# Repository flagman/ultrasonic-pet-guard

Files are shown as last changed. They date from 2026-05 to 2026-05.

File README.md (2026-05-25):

# Ultrasonic Pet Guard

An open-source, 3D-printed **ultrasonic deterrent for dogs and cats**, built around an ESP32. A PIR sensor watches a zone (a doorway, a couch, a corner the dog keeps marking); when it detects motion during the active hours, the device fires a short burst of loud **25 kHz** sound — inaudible to humans, very unpleasant to the animal — so the pet learns to stay away.

It is deliberately *loud*. The ESP32 drives the ultrasonic transducer through an L298N in a **full H-bridge** off a **12 V** supply, which is what makes the burst strong enough that a dog will actually break off and leave the zone rather than just twitch an ear.

| Real device | Concept render | Fusion 360 (CAD) |
|---|---|---|
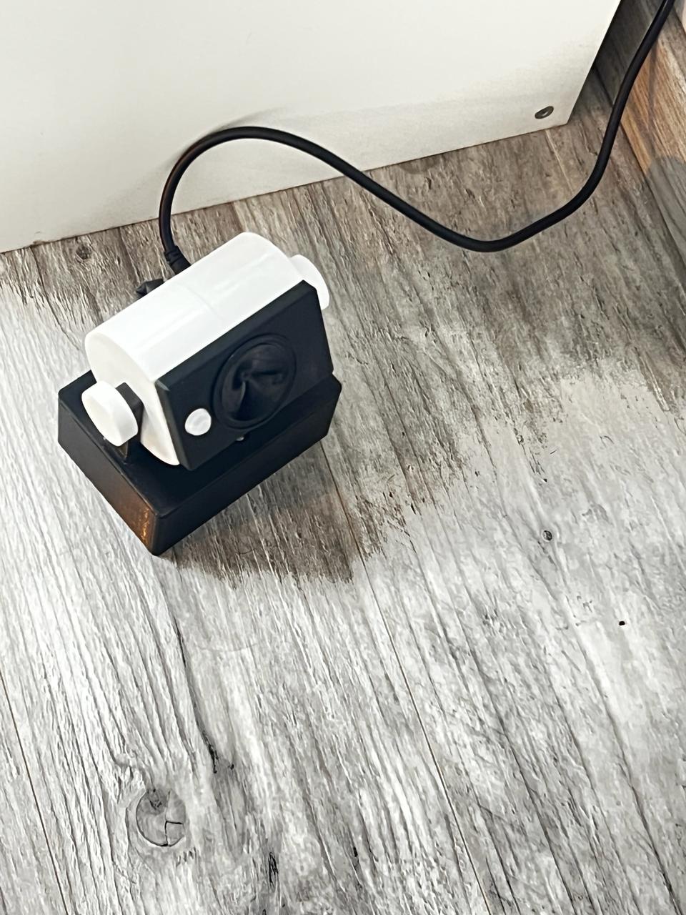
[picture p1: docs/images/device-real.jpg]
Real 3D-printed device
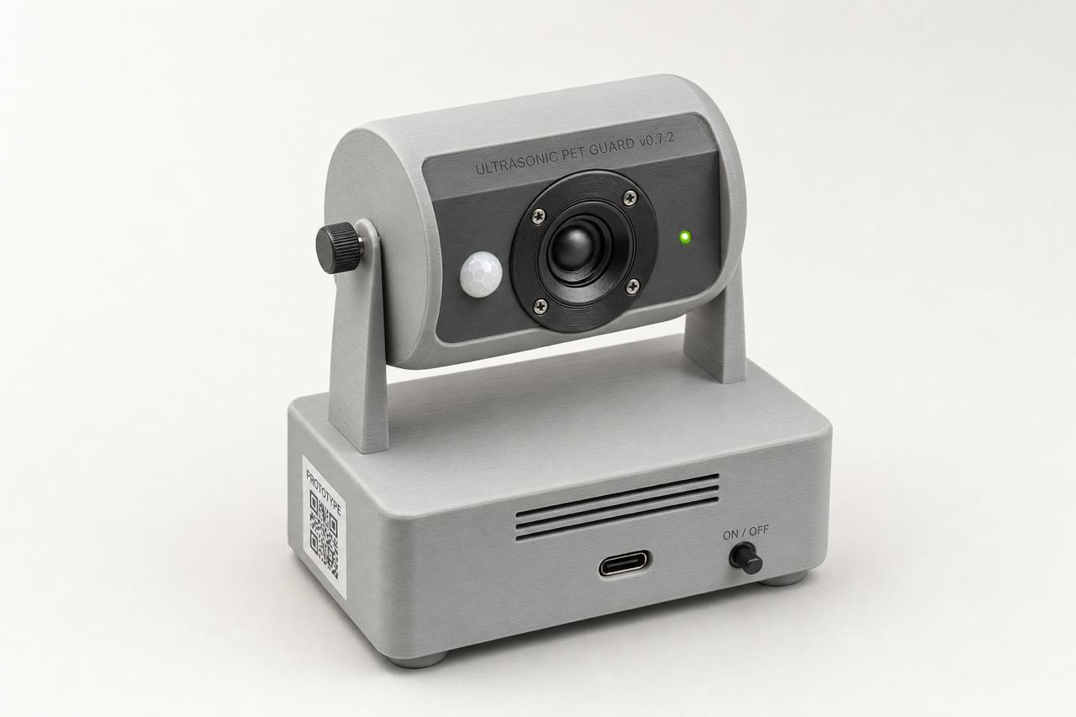
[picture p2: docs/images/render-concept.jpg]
Studio concept render
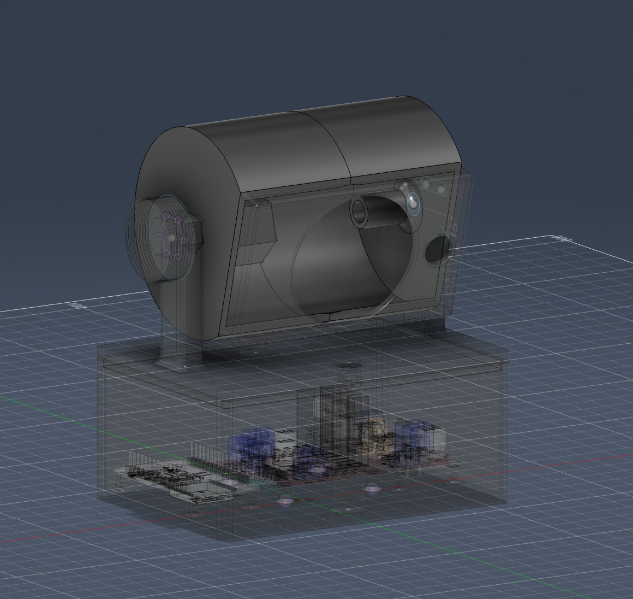
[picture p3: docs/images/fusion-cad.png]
Fusion 360 CAD view
|  |  |  |

> ⚠️ **Use responsibly.** This is an aversive device. It is meant to keep a pet out of a specific spot, not to punish or harm. Only run it on the active-hours schedule, point it at the zone (not at where the animal rests/sleeps), and dial back the burst if your pet is simply distressed rather than redirected. Do not aim it at people or use it where it could affect other animals you don't intend to.

---

## How it works (and why it hits so hard)

Several design choices stack up to make the output far stronger than a typical AliExpress repeller:

- **Full H-bridge drive (±Vsupply instead of 0..Vsupply).** The L298N is driven with IN1 carrying the PWM and IN3 carrying the *inverted* PWM (routed through the ESP32 GPIO matrix). The transducer sees the full supply swing in *both* directions — that's 2× the voltage swing, ≈4× the acoustic power, **+6 dB** for free versus a single-ended driver.
- **12 V supply.** Running the H-bridge at 12 V (not 5 V) raises the SPL much further again — this is the single biggest reason the built device is so loud.
- **Hardware PWM (LEDC).** The 25 kHz square wave is generated by the ESP32's hardware timer, so the frequency is rock-steady with no software jitter.
- **25 kHz, chosen empirically.** Inaudible to humans (>20 kHz), well within a dog's hearing, and reproduced efficiently by a real ultrasonic piezo tweeter. 25 kHz gave the sharpest real-world reaction in testing.
- **Pulsed burst, not a steady tone.** 10 pulses of 300 ms with 150 ms gaps. The on/off pattern triggers a startle response and prevents the animal from habituating the way it would to a continuous tone.
- **Dedicated ultrasonic piezo transducer**, well sealed in the enclosure and aimed outward, so the energy goes into the room instead of leaking back inside the case.

See [`docs/HARDWARE.md`](docs/HARDWARE.md) for the parts list (BOM), wiring, and print settings.

## Features

- PIR-triggered 25 kHz ultrasonic burst (10 × 300 ms).
- **Web UI** over WiFi (`http://pet-guard.local/`) to set the active-hours window and fire a test burst.
- **NTP-synced schedule** (e.g. 21:00 → 07:00, may cross midnight), stored in NVS so it survives reboots.
- **Fail-safe:** if WiFi/NTP is unavailable, the device runs 24/7 instead of going dark.
- JSON status endpoint at `/api/status`.
- Tilting "drum head" on a friction-clamped M8 pivot bolt so you can aim it precisely.

## Repository layout

```
.
├── src/main.cpp                 ESP32 firmware (PlatformIO / Arduino framework)
├── include/
│   ├── config.example.h         WiFi credentials template — copy to config.h
│   └── config.h                 your local credentials (gitignored)
├── platformio.ini               PlatformIO project config
├── hardware/
│   ├── cad/                     Fusion 360 STEP export
│   └── print/                   ready-to-slice 3MF parts
├── docs/
│   ├── HARDWARE.md              BOM, wiring, and print settings
│   └── images/                  photos & renders
└── README.md
```

## Bill of materials

### Electronics

| Qty | Part | Notes |
|---|---|---|
| 1 | ESP32 DevKit (ESP32-WROOM-32) | the controller |
| 1 | L298N dual H-bridge module | drives the transducer in full H-bridge |
| 1 | AM312 PIR motion sensor | 3-pin (VCC / GND / OUT) |
| 1 | Wide-band piezo tweeter, Ø50 mm | pick a unit that reproduces well past 25 kHz (e.g. **~1–45 kHz**), **not** one capped at 25 kHz; bonded in with hot-melt glue |
| 1 | **12 V DC power adapter, ≥1–2 A** | powers the H-bridge at 12 V (high SPL) |
| 1 | **12 V barrel-jack socket** (panel mount, 5.5 × 2.1 mm) | power input on the enclosure |
| 1 | **DC-DC step-down (buck) converter — XL4015** | drops 12 V → 5 V for the ESP32, PIR, and L298N logic |
| ~3 m | Hookup wire (AWG 28–30) + heat-shrink | internal wiring harness |

> The build is powered by **12 V via the barrel jack**. The 12 V feeds the L298N motor supply (`Vs`) directly (for high SPL), while an **XL4015 buck converter steps 12 V down to 5 V**. That single 5 V rail powers the **ESP32 (`5V` pin), the PIR sensor (`VCC`), and the L298N logic (`+5V`)** — so the L298N's onboard 5 V regulator is not used (set the XL4015 output trimmer to 5 V before connecting anything). During flashing you can also power the ESP32 over USB.

> **Note:** the power LED and on/off switch visible in the concept render are **not** part of the current enclosure design (no cutouts or mounts, and the firmware does not drive an LED). Power is switched at the 12 V adapter. Add your own panel cutouts if you want them.

### 3D-printed parts (`hardware/print/`)

| File | Part |
|---|---|
| `body.3mf` | base shell (electronics bay) |
| `top-plate.3mf` | top plate / head module with yokes |
| `drum-left.3mf`, `drum-right.3mf` | drum-head halves |
| `front-panel.3mf` | front insert / chord face (PIR + transducer cutouts) |
| `bolt-holder.3mf` | tilt pivot / captured M8-nut holder |

Print in **PETG**, 0.2 mm layers, 100 % infill. Print settings and the part list are in [`docs/HARDWARE.md`](docs/HARDWARE.md).

### Fasteners & hardware

| Qty | Part | Notes |
|---|---|---|
| 2 | **M8 bolt** | tilt pivot — one through each yoke |
| 1 | **M8 extended (coupling) nut** | captured in one drum end; the M8 tilt bolt threads into it to clamp the tilt by friction (the other drum end is a plain Ø8 hole) |
| 1 | **M3 heat-set brass insert** | holds the top-plate |
| 6–8 | **Ø1.75 mm self-tapping plastic screws** | mounting the PCBs (ESP32 / L298N / XL4015) |
| 1 | cable grommet Ø10 mm | base↔drum harness pass-through |
| 4 | self-adhesive rubber feet | base |
| — | **Hot-melt glue** | bonding the PIR sensor + tweeter into the front panel |
| — | **Superglue (CA)** | joining the two drum halves + the front panel |

## Firmware: build & flash (PlatformIO)

1. Install [PlatformIO](https://platformio.org/) (VS Code extension or `pip install platformio`).
2. Set your WiFi credentials (kept out of git):
   ```sh
   cp include/config.example.h include/config.h
   # then edit include/config.h with your SSID and password
   ```
   WiFi is optional — it is only used for NTP (the schedule) and the web UI. Without it the device runs 24/7.
3. Connect the ESP32 over USB and build + upload:
   ```sh
   pio run --target upload
   ```
4. Watch the serial log (optional):
   ```sh
   pio device monitor -b 115200
   ```

## Wiring / pinout

| Signal | ESP32 GPIO | To |
|---|---|---|
| PIR `OUT` | **27** | AM312 OUT |
| L298N `IN1` | **13** | H-bridge input (non-inverted PWM) |
| L298N `IN3` | **12** | H-bridge input (inverted PWM, via GPIO matrix) |
| L298N `ENA` (+`ENB`) | **14** | shared H-bridge enable |
| L298N `IN2`, `IN4` | — | **tie both to GND** (unused half-bridge inputs — must not float) |
| Transducer | — | across L298N **OUT1 ↔ OUT3** |
| 12 V rail | — | barrel jack → L298N `Vs` (motor supply) **and** → XL4015 buck input |
| 5 V rail (XL4015 `OUT`) | — | → ESP32 `5V`, → PIR `VCC`, **and** → L298N `+5V` logic |

The piezo is connected **between OUT1 and OUT3** (not to ground) — that is what gives the full H-bridge ±12 V swing. Only `IN1`/`IN3` are driven; the other two inputs `IN2` and `IN4` (which control the unused outputs OUT2/OUT4) must be **tied to GND** so they don't float and cause erratic switching.

## Using it

- Open **`http://pet-guard.local/`** (or the IP printed on the serial log) from any phone/laptop on the same network.
- Set the **active window** (default 21:00 → 07:00; it may cross midnight), toggle **Enabled**, and **Save** — the schedule is stored on the device.
- Hit **Test (fire burst now)** to verify the transducer. You won't hear the 25 kHz tone; confirm it with a spectrum-analyzer phone app, or just watch the pet's reaction.

## License

[MIT](LICENSE) — firmware, hardware files, and documentation. Build it, modify it, share it.

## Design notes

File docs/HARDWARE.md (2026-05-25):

# Ultrasonic Pet Guard — Hardware

Parts list, wiring, and print settings. The geometry and assembly are defined by
the CAD (`hardware/cad/`) and the print files (`hardware/print/`).

## Electronics

| Component | Key spec |
|---|---|
| ESP32 DevKit | ESP32-WROOM-32, USB-C (~52 × 28.7 mm) |
| L298N dual H-bridge module | with heatsink (~43.5 × 43.5 × 26 mm) |
| AM312 PIR sensor | 3-pin (VCC / GND / OUT), dome Ø13.4 mm |
| Wide-band piezo tweeter | Ø50 × 18 mm, ~1–45 kHz (must reproduce 25 kHz well — **not** a unit capped at 25 kHz) |
| 12 V DC adapter | ≥ 1–2 A, 5.5 × 2.1 mm barrel plug |
| 12 V barrel-jack socket | panel-mount, 5.5 × 2.1 mm |
| XL4015 DC-DC buck | 12 V → 5 V step-down |
| Silicone hookup wire + heat-shrink | AWG 28–30, ~3 m |

> The LED and on/off switch shown in the concept render are **not** in the current enclosure design (no cutouts; firmware drives no LED). Power is switched at the adapter.

## Fasteners & adhesives

| Part | Qty | Use |
|---|---|---|
| M8 bolt | 2 | tilt pivot (one per yoke) |
| M8 extended (coupling) nut | 1 | captured in one drum end; the M8 bolt threads into it (other end is a plain Ø8 hole) |
| M3 heat-set brass insert | 1 | holds the top-plate |
| M2.5 × 6 countersunk screw | 4 | bottom cover ↔ base |
| Ø1.75 mm self-tapping screws | 6–8 | ESP32, L298N, XL4015 into the printed standoffs |
| Cable grommet Ø10 mm | 1 | base↔drum harness pass-through |
| Rubber feet | 4 | base |
| Hot-melt glue | — | PIR + tweeter into the front panel |
| Superglue (CA) | — | drum halves + front panel |

## Wiring

**Pinout (ESP32):**

| GPIO | To |
|---|---|
| 27 | PIR `OUT` |
| 13 | L298N `IN1` (PWM) |
| 12 | L298N `IN3` (inverted PWM, via GPIO matrix) |
| 14 | L298N `ENA` + `ENB` |

- L298N `IN2` and `IN4` → **GND** (unused inputs, must not float).
- Transducer connects **across L298N OUT1 ↔ OUT3** (full H-bridge).

**Power:**

```
12 V adapter → barrel jack ─┬→ L298N Vs (12 V → H-bridge / piezo)
                            └→ XL4015 buck (12 V → 5 V) ─┬→ ESP32 5V
                                                          ├→ L298N +5V (logic)
                                                          └→ PIR VCC
common GND
```

Set the XL4015 output trimmer to 5 V before wiring it to anything. The L298N's onboard 5 V regulator is not used.

## Printing

- FDM, 0.4 mm nozzle, **PETG**.
- Layers: **0.2 mm** (all parts).
- Infill: **100 %**.
- Print files (`hardware/print/`): `body`, `top-plate`, `drum-left`, `drum-right`, `front-panel`, `bolt-holder`.

## Assembly notes

- The ESP32 is mounted **upside down** in the base (board flipped onto its standoffs).
- Heat-set the single M3 insert into the base that holds the top-plate; capture the extended M8 nut in one drum end.
- Hot-glue the PIR and the tweeter into the front panel; superglue the two drum halves and the front panel.
- Route the harness out through the drum's hollow stub axle and the base grommet before closing up.
- Mount the drum on the two M8 bolts; tighten the bolt on the captured-nut side to set the tilt friction.

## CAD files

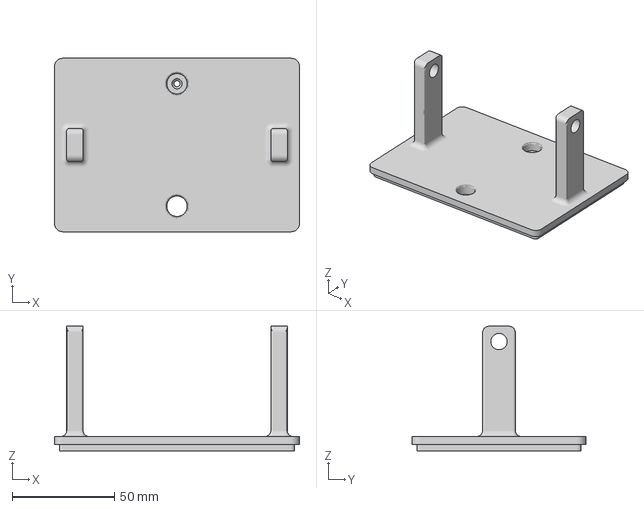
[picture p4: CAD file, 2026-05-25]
hardware/print/top-plate.3mf
120.0 x 85.0 x 61.0 mm

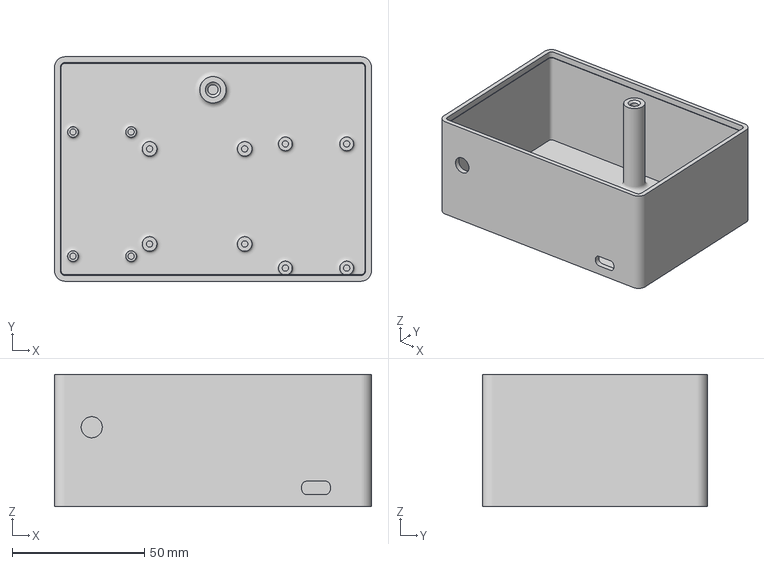
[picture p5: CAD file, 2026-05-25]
hardware/print/body.3mf
120.0 x 85.0 x 50.0 mm

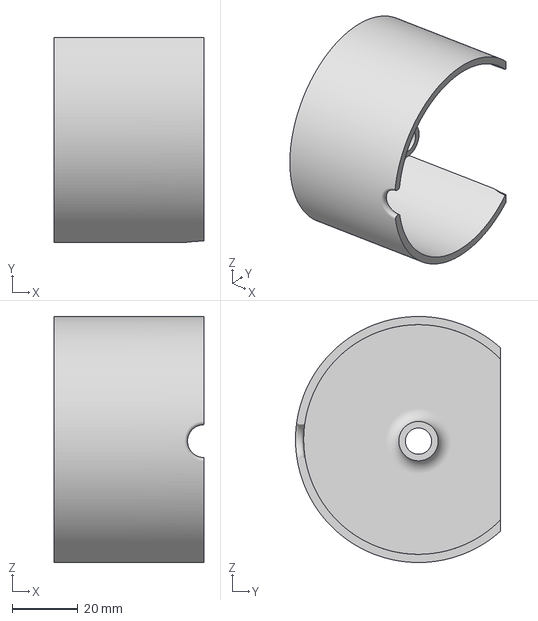
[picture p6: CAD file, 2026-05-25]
hardware/print/drum-right.3mf
45.7 x 62.5 x 75.0 mm

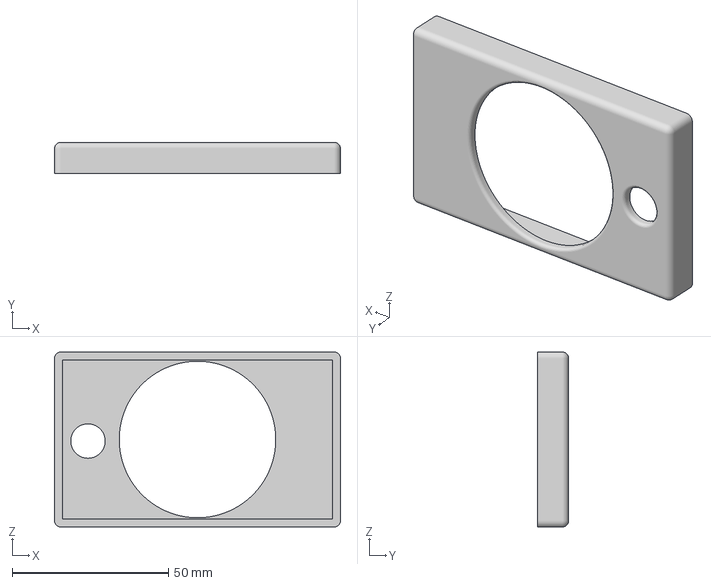
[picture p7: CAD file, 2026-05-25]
hardware/print/front-panel.3mf
91.4 x 10.0 x 55.9 mm

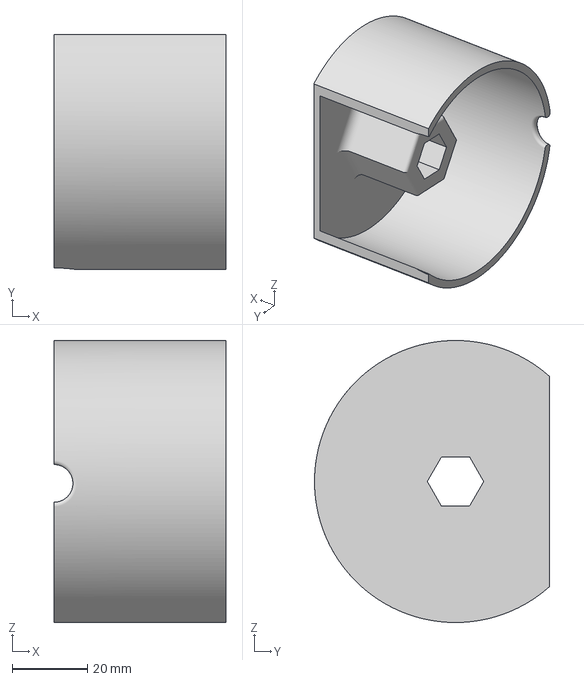
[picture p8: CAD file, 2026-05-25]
hardware/print/drum-left.3mf
45.7 x 62.5 x 75.0 mm

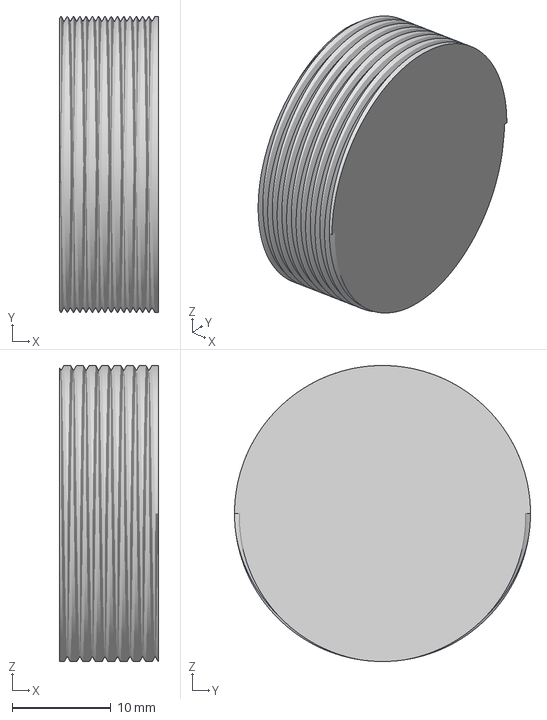
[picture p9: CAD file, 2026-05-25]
hardware/print/bolt-holder.3mf
10.0 x 30.0 x 30.0 mm

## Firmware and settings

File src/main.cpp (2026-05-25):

#include <Arduino.h>
#include <WiFi.h>
#include <WebServer.h>
#include <ESPmDNS.h>
#include <Preferences.h>
#include <time.h>
#include <rom/gpio.h>             // gpio_matrix_out — routes a peripheral signal onto a GPIO
#include <soc/gpio_sig_map.h>     // LEDC_HS_SIG_OUT0_IDX — LEDC signal index
#include "config.h"               // WiFi credentials (copied from config.example.h, gitignored)

void playUltrasound(int durationMs);
void playTone(uint32_t freqHz, int durationMs);
bool isActiveNow();
void fireBurst();
void loadSchedule();
void saveSchedule();
void handleRoot();
void handleSave();
void handleTest();
void handleStatus();
// ==========================================
// ULTRASONIC BARRIER FOR DOGS (ESP32)
// ==========================================

// Pin assignments
const int pirPin = 27;    // AM312 motion sensor
const int in1Pin = 13;   // L298N IN1 — LEDC, non-inverted
const int in3Pin = 12;   // L298N IN3 — LEDC, inverted (full H-bridge between OUT1 and OUT3)
const int enaPin = 14;    // L298N ENA + ENB (tied together on the module) — shared enable
// NOTE: L298N IN2 and IN4 (the unused half-bridge inputs driving OUT2/OUT4) are
// tied to GND in hardware so they don't float. They are not driven by the ESP32.

// LEDC: ESP32 hardware PWM (generates the square wave itself, no jitter from FreeRTOS)
const int ledcChannel = 0;
const int ledcFreqUltrasound = 25000;  // 25 kHz — operating frequency
const int ledcResolution = 8;          // 8-bit: duty 0..255

// --- WiFi / NTP ---
const char* wifiSsid     = WIFI_SSID;      // defined in config.h
const char* wifiPassword = WIFI_PASSWORD;  // defined in config.h
const char* ntpServer    = "pool.ntp.org";
// POSIX TZ for Warsaw: CET (UTC+1) in winter, CEST (UTC+2) in summer.
// M3.5.0 = last Sunday of March, M10.5.0/3 = last Sunday of October at 03:00.
const char* tzPosix      = "CET-1CEST,M3.5.0,M10.5.0/3";

// --- Active operating window (editable through the web UI) ---
uint8_t startHour   = 21;
uint8_t startMinute = 0;
uint8_t endHour     = 7;
uint8_t endMinute   = 0;
bool    scheduleEnabled = true;   // global kill switch
unsigned long lastTriggerMs = 0;  // shown in the UI

// Flag: did the time sync succeed? If not, run 24/7 (fail-safe).
bool timeSynced = false;

// --- Web server + NVS ---
WebServer   server(80);
Preferences prefs;
const char* mdnsHost = "pet-guard";  // → http://pet-guard.local

void setup() {
  Serial.begin(115200);
  delay(100);
  Serial.println();
  Serial.println("=== Ultrasonic Pet Guard ===");
  Serial.printf("PIR: GPIO %d | IN1: GPIO %d | IN3: GPIO %d | ENA: GPIO %d\n",
                pirPin, in1Pin, in3Pin, enaPin);
  Serial.printf("LEDC: ch %d, freq %d Hz, %d-bit\n",
                ledcChannel, ledcFreqUltrasound, ledcResolution);

  // Load the schedule from NVS (defaults: 21:00 → 07:00, enabled).
  loadSchedule();
  Serial.printf("Loaded schedule: %02u:%02u - %02u:%02u, enabled=%s\n",
                startHour, startMinute, endHour, endMinute,
                scheduleEnabled ? "yes" : "no");

  // Pin setup
  pinMode(pirPin, INPUT);
  pinMode(in1Pin, OUTPUT);
  pinMode(in3Pin, OUTPUT);
  pinMode(enaPin, OUTPUT);

  // Make sure the speaker AND the amplifier are off at boot
  digitalWrite(in1Pin, LOW);
  digitalWrite(in3Pin, LOW);
  digitalWrite(enaPin, LOW); // hard-mute the L298N!

  // LEDC: one channel, two pins driven in antiphase.
  // IN1 gets the direct square wave; IN3 gets the same signal inverted
  // through the ESP32 GPIO matrix. This forms a full H-bridge between OUT1
  // and OUT3, i.e. ±Vsupply across the piezo instead of 0..Vsupply (+6 dB).
  ledcSetup(ledcChannel, ledcFreqUltrasound, ledcResolution);
  ledcAttachPin(in1Pin, ledcChannel);
  gpio_matrix_out(in3Pin, LEDC_HS_SIG_OUT0_IDX + ledcChannel, true, false);
  ledcWrite(ledcChannel, 0); // silent at boot (ENA is LOW anyway)

  // --- WiFi + NTP ---
  Serial.printf("Connecting to WiFi \"%s\"", wifiSsid);
  WiFi.mode(WIFI_STA);
  WiFi.begin(wifiSsid, wifiPassword);
  unsigned long wifiStart = millis();
  while (WiFi.status() != WL_CONNECTED && millis() - wifiStart < 15000) {
    delay(500);
    Serial.print(".");
  }
  Serial.println();

  if (WiFi.status() == WL_CONNECTED) {
    Serial.printf("WiFi OK, IP: %s, RSSI: %d dBm\n",
                  WiFi.localIP().toString().c_str(), WiFi.RSSI());

    configTzTime(tzPosix, ntpServer);
    struct tm tinfo;
    if (getLocalTime(&tinfo, 5000)) {
      timeSynced = true;
      Serial.printf("Time synced: %04d-%02d-%02d %02d:%02d:%02d %s\n",
                    tinfo.tm_year + 1900, tinfo.tm_mon + 1, tinfo.tm_mday,
                    tinfo.tm_hour, tinfo.tm_min, tinfo.tm_sec,
                    tinfo.tm_isdst > 0 ? "CEST" : "CET");
      Serial.printf("Active window: %02u:%02u - %02u:%02u\n",
                    startHour, startMinute, endHour, endMinute);
    } else {
      Serial.println("NTP sync failed — falling back to 24/7 mode");
    }

    // mDNS: open http://pet-guard.local/ from a phone/laptop browser.
    if (MDNS.begin(mdnsHost)) {
      MDNS.addService("http", "tcp", 80);
      Serial.printf("mDNS started: http://%s.local/\n", mdnsHost);
    } else {
      Serial.println("mDNS start failed");
    }

    server.on("/",          HTTP_GET,  handleRoot);
    server.on("/save",      HTTP_POST, handleSave);
    server.on("/test",      HTTP_POST, handleTest);
    server.on("/api/status", HTTP_GET, handleStatus);
    server.begin();
    Serial.printf("Web UI: http://%s/\n", WiFi.localIP().toString().c_str());
  } else {
    Serial.println("WiFi failed — falling back to 24/7 mode, no web UI");
  }

  // Give the motion sensor time to calibrate
  Serial.println("PIR warmup (2s)...");
  delay(2000);
  Serial.println("Ready. Waiting for motion.");
}

// Active operating window (minute resolution, may cross midnight).
// If the time is not synced — always active (fail-safe), but only when scheduleEnabled.
bool isActiveNow() {
  if (!scheduleEnabled) return false;
  if (!timeSynced) return true;
  struct tm tinfo;
  if (!getLocalTime(&tinfo, 50)) return true;

  int nowMins   = tinfo.tm_hour * 60 + tinfo.tm_min;
  int startMins = startHour     * 60 + startMinute;
  int endMins   = endHour       * 60 + endMinute;

  if (startMins == endMins) return false;                 // empty window
  if (startMins <  endMins) return nowMins >= startMins && nowMins < endMins;
  return nowMins >= startMins || nowMins < endMins;       // crosses midnight
}

// Load/save the schedule in NVS (survives reboots).
void loadSchedule() {
  prefs.begin("pet-guard", true);  // read-only
  startHour       = prefs.getUChar("sH", 21);
  startMinute     = prefs.getUChar("sM", 0);
  endHour         = prefs.getUChar("eH", 7);
  endMinute       = prefs.getUChar("eM", 0);
  scheduleEnabled = prefs.getBool("on",  true);
  prefs.end();
}

void saveSchedule() {
  prefs.begin("pet-guard", false); // RW
  prefs.putUChar("sH", startHour);
  prefs.putUChar("sM", startMinute);
  prefs.putUChar("eH", endHour);
  prefs.putUChar("eM", endMinute);
  prefs.putBool ("on", scheduleEnabled);
  prefs.end();
}

// A burst of 10 ultrasonic pulses. Factored out so it can be triggered both
// from loop() and from the "Test" button in the web UI.
void fireBurst() {
  lastTriggerMs = millis();
  for (int i = 0; i < 10; i++) {
    playUltrasound(300);
    delay(150);
  }
}

// ----- Web handlers ---------------------------------------------------------

static String hhmm(uint8_t h, uint8_t m) {
  char buf[6];
  snprintf(buf, sizeof(buf), "%02u:%02u", h, m);
  return String(buf);
}

void handleRoot() {
  struct tm tinfo;
  bool haveTime = timeSynced && getLocalTime(&tinfo, 50);
  String nowStr = haveTime
    ? String(tinfo.tm_hour < 10 ? "0" : "") + tinfo.tm_hour + ":" +
      String(tinfo.tm_min  < 10 ? "0" : "") + tinfo.tm_min
    : String("--:--");
  bool active = isActiveNow();

  String html;
  html.reserve(2500);
  html += F(
    "<!doctype html><html><head><meta charset=\"utf-8\">"
    "<meta name=\"viewport\" content=\"width=device-width,initial-scale=1\">"
    "<title>Pet Guard</title>"
    "<style>"
    "body{font-family:system-ui,sans-serif;max-width:420px;margin:24px auto;"
    "padding:0 16px;color:#1f2937}"
    "h1{font-size:20px;margin:0 0 16px}"
    "fieldset{border:1px solid #e5e7eb;border-radius:8px;padding:12px 16px;"
    "margin:0 0 16px}"
    "legend{font-size:13px;color:#6b7280;padding:0 6px}"
    "label{display:block;margin:10px 0 4px;font-size:14px}"
    "input[type=time]{font-size:18px;padding:6px 8px;width:130px;"
    "border:1px solid #d1d5db;border-radius:6px}"
    "button{padding:10px 16px;font-size:15px;border-radius:6px;border:0;"
    "background:#2563eb;color:#fff;cursor:pointer;width:100%}"
    "button.secondary{background:#64748b;margin-top:12px}"
    ".badge{display:inline-block;padding:6px 10px;border-radius:999px;"
    "font-size:13px;font-weight:600}"
    ".on{background:#dcfce7;color:#166534}"
    ".off{background:#fee2e2;color:#991b1b}"
    ".row{display:flex;align-items:center;gap:8px;margin:6px 0}"
    ".muted{color:#6b7280;font-size:13px;margin-top:8px}"
    "</style></head><body>"
    "<h1>Ultrasonic Pet Guard</h1>"
  );
  html += "<div class=\"row\"><span class=\"badge ";
  html += active ? "on\">ACTIVE" : "off\">IDLE";
  html += "</span><span>Now: <b>" + nowStr + "</b>";
  if (haveTime) html += tinfo.tm_isdst > 0 ? " CEST" : " CET";
  html += "</span></div>";

  html += "<form action=\"/save\" method=\"POST\"><fieldset><legend>Schedule</legend>";
  html += "<label><input type=\"checkbox\" name=\"enabled\"";
  if (scheduleEnabled) html += " checked";
  html += "> Enabled</label>";
  html += "<label>Start time</label><input type=\"time\" name=\"start\" value=\"" + hhmm(startHour, startMinute) + "\">";
  html += "<label>End time</label><input type=\"time\" name=\"end\" value=\"" + hhmm(endHour, endMinute) + "\">";
  html += "<div class=\"muted\">Window may cross midnight (e.g. 21:00 → 07:00).</div>";
  html += "</fieldset><button type=\"submit\">Save</button></form>";

  html += "<form action=\"/test\" method=\"POST\">"
          "<button class=\"secondary\" type=\"submit\">Test (fire burst now)</button></form>";

  html += "<p class=\"muted\">WiFi: " + WiFi.SSID() + " (" + WiFi.RSSI() + " dBm)<br>";
  html += "IP: " + WiFi.localIP().toString() + "<br>";
  html += "Uptime: " + String(millis() / 1000) + " s</p>";
  html += "</body></html>";

  server.send(200, "text/html; charset=utf-8", html);
}

static bool parseHHMM(const String& s, uint8_t& h, uint8_t& m) {
  int colon = s.indexOf(':');
  if (colon < 1) return false;
  int hh = s.substring(0, colon).toInt();
  int mm = s.substring(colon + 1).toInt();
  if (hh < 0 || hh > 23 || mm < 0 || mm > 59) return false;
  h = (uint8_t)hh;
  m = (uint8_t)mm;
  return true;
}

void handleSave() {
  uint8_t sH, sM, eH, eM;
  if (!parseHHMM(server.arg("start"), sH, sM) ||
      !parseHHMM(server.arg("end"),   eH, eM)) {
    server.send(400, "text/plain", "Bad time format");
    return;
  }
  startHour       = sH;
  startMinute     = sM;
  endHour         = eH;
  endMinute       = eM;
  scheduleEnabled = server.hasArg("enabled");
  saveSchedule();

  Serial.printf("Schedule updated: %s -> %s, enabled=%s\n",
                hhmm(startHour, startMinute).c_str(),
                hhmm(endHour,   endMinute).c_str(),
                scheduleEnabled ? "yes" : "no");

  server.sendHeader("Location", "/", true);
  server.send(303);
}

void handleTest() {
  Serial.println("Manual test fire (web)");
  fireBurst();
  server.sendHeader("Location", "/", true);
  server.send(303);
}

void handleStatus() {
  struct tm tinfo;
  bool haveTime = timeSynced && getLocalTime(&tinfo, 50);
  String json = "{";
  json += "\"enabled\":";        json += scheduleEnabled ? "true" : "false";
  json += ",\"active\":";        json += isActiveNow()    ? "true" : "false";
  json += ",\"start\":\"" + hhmm(startHour, startMinute) + "\"";
  json += ",\"end\":\""   + hhmm(endHour,   endMinute)   + "\"";
  json += ",\"now\":\"";
  if (haveTime) {
    char buf[20];
    snprintf(buf, sizeof(buf), "%04d-%02d-%02dT%02d:%02d:%02d",
             tinfo.tm_year + 1900, tinfo.tm_mon + 1, tinfo.tm_mday,
             tinfo.tm_hour, tinfo.tm_min, tinfo.tm_sec);
    json += buf;
  }
  json += "\",\"uptimeMs\":";   json += millis();
  json += ",\"lastTriggerMs\":"; json += lastTriggerMs;
  json += ",\"rssi\":";          json += WiFi.RSSI();
  json += "}";
  server.send(200, "application/json", json);
}

void loop() {
  server.handleClient();  // service HTTP requests (no-op if WiFi never came up)

  static int lastPirState = LOW;
  int pirState = digitalRead(pirPin);

  if (pirState != lastPirState) {
    Serial.printf("[%lu ms] PIR -> %s\n", millis(), pirState ? "HIGH" : "LOW");
    lastPirState = pirState;
  }

  if (pirState == HIGH) {
    if (!isActiveNow()) {
      struct tm tinfo;
      if (getLocalTime(&tinfo, 50)) {
        Serial.printf("[%02d:%02d] Motion ignored (window %02u:%02u-%02u:%02u, enabled=%s)\n",
                      tinfo.tm_hour, tinfo.tm_min,
                      startHour, startMinute, endHour, endMinute,
                      scheduleEnabled ? "yes" : "no");
      }
      delay(1000); // light debounce so the log isn't flooded
      return;
    }

    Serial.println("Motion! Firing ultrasound burst (10 x 300ms)");
    fireBurst();

    Serial.println("Cooldown 5s...");
    // 5 s cooldown, but keep answering HTTP (sliced into 50 ms delays)
    unsigned long until = millis() + 5000;
    while ((long)(millis() - until) < 0) {
      server.handleClient();
      delay(50);
    }
    Serial.println("Ready.");
  }
}

// -------------------------------------------------------------------
// ULTRASOUND generation (25 kHz) — inaudible to humans
// -------------------------------------------------------------------
void playUltrasound(int durationMs) {
  playTone(ledcFreqUltrasound, durationMs);
}

// -------------------------------------------------------------------
// Shared helper: plays a square wave of the given frequency in full H-bridge.
// The LEDC routing (IN1 direct, IN3 inverted) is configured once in setup().
// Here we only change the frequency, start the PWM, and toggle ENA.
// -------------------------------------------------------------------
void playTone(uint32_t freqHz, int durationMs) {
  ledcSetup(ledcChannel, freqHz, ledcResolution); // re-tune the channel frequency
  ledcWrite(ledcChannel, 128);                     // 50% duty — clean square wave
  digitalWrite(enaPin, HIGH);                      // H-bridge outputs go active

  delay(durationMs);

  // ORDER MATTERS: mute the H-bridge first (outputs → HIGH-Z), and only then
  // stop the LEDC. Otherwise at duty=0 in1Pin sits LOW while in3Pin (inverted)
  // sits HIGH → a sustained DC level across the piezo on shutdown.
  // (The abrupt on/off transient at each burst edge is inherent to this
  // rail-to-rail drive — there is no amplitude envelope — and is not addressed
  // here; it's harmless for an ultrasonic burst.)
  digitalWrite(enaPin, LOW);
  ledcWrite(ledcChannel, 0);
}

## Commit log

2026-05-25 Initial public release: Ultrasonic Pet Guard
    ESP32 firmware (PlatformIO) + 3D-printable enclosure for a PIR-triggered
    25 kHz ultrasonic dog/cat deterrent. Full H-bridge drive off 12 V, WiFi web
    UI with NTP-synced active-hours schedule, fail-safe 24/7 fallback.
    - English README with how-it-works, BOM, wiring, print & flash instructions
    - docs/HARDWARE.md: full hardware spec, dimensions, assembly (12 V build)
    - hardware/: STEP CAD export + ready-to-slice 3MF parts
    - WiFi credentials moved to gitignored include/config.h (config.example.h template)
    [body.3mf, bolt-holder.3mf, drum-left.3mf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]
2026-05-25 docs: add XL4015 buck converter to power chain
    The ESP32 is powered by an XL4015 DC-DC step-down (12 V -> 5 V), not the
    L298N onboard regulator. Correct the BOM, power diagram, wiring, and
    assembly steps in README.md and docs/HARDWARE.md.
2026-05-25 docs: correct drum tilt hardware to M8 bolt + captured nut
    The drum tilt is an M8 bolt threading into an extended (coupling) M8 nut
    captured in one drum end; the other end is a plain Ø8 hole. No nylon
    washers and no M3 brass inserts in the drum. Update BOM, tilt-mechanism
    diagram, lock description, holding-torque estimate, and assembly steps in
    README.md and docs/HARDWARE.md.
2026-05-25 docs: drop LED/switch from current design; widen tweeter spec
    - The 3 mm LED and on/off switch are concept-render only and are not
    modeled into the current enclosure (no cutouts/mounts; firmware drives
    no LED). Mark them as not-designed-in across BOM, pinout, diagrams, and
    assembly steps.
    - Transducer must be a wide-band piezo tweeter (~1-45 kHz) that reproduces
    25 kHz well, not a unit capped at 25 kHz. Fix E4 and the README BOM.
2026-05-25 docs: specify L298N IN2/IN4 must be tied to GND
    Only IN1/IN3 are driven (full H-bridge across OUT1/OUT3); the unused
    inputs IN2 and IN4 must be grounded so they don't float. Add to README
    wiring table + note, HARDWARE.md power section, and a main.cpp comment.
2026-05-25 docs: correct mounting method to glue (hot-melt + superglue)
    PIR and the tweeter are bonded with hot-melt glue (no screws or brass
    inserts). The two drum halves and the front panel are joined with
    superglue (CA). Update README BOM/fasteners and HARDWARE.md parts (P3/P4),
    E4, assembly steps, and drop the obsolete H1a speaker screws.
2026-05-25 docs: clarify 5 V rail feeds ESP32, PIR, and L298N logic
    The XL4015 buck 5 V output is a single rail powering the ESP32 (5V), the
    PIR (VCC), and the L298N logic (+5V) — the L298N onboard regulator is not
    used. Update README wiring table + notes and HARDWARE.md power diagram.
2026-05-25 docs: remove waveguide horn; fix DC-DC mounting & wire length
    - Remove the optional waveguide horn (P5) entirely: part row, part count,
    chord diagram label, and print step.
    - H5 self-tapping screws also mount the XL4015 buck (qty 6-8).
    - Silicone hookup wire: ~3 m (was ~1 m).
2026-05-25 docs: trim HARDWARE.md to bare minimum
    Drop design rationale, tilt-mechanism geometry/diagrams, holding-torque
    estimates, the assembly narrative, and the invented P-code parts list.
    Keep only BOM, wiring/pinout, power, print settings, and a few build
    notes. Update README references accordingly.
2026-05-25 docs: print settings are PETG, 0.2 mm layers, 100% infill
    Correct the print parameters (all parts) and drop the inaccurate
    time/material estimate that assumed low infill. Update README and
    HARDWARE.md.
2026-05-25 docs: note ESP32 is mounted upside down
2026-05-25 docs: fix top-plate to a single M3 heat-set insert (not 4)
2026-05-25 docs: PIR + tweeter are hot-glued into the front panel, not the drum
2026-05-25 docs: base-to-drum cable grommet is Ø10 mm (not Ø5)
2026-05-25 docs: add Fusion 360 CAD render to README gallery
2026-05-25 firmware: clarify the playTone shutdown comment
    The ENA-before-LEDC order prevents a sustained DC level across the piezo
    on shutdown, not clicks in general. The on/off transient at each burst
    edge is inherent to the rail-to-rail drive and is not addressed.
    [main.cpp]
